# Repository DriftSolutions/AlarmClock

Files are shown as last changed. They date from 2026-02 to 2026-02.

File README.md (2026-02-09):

# Touchscreen Alarm Clock

A 3D printed touchscreen alarm clock with Home Assistant integration, designed for Raspberry Pi with a 5" display.

Pull Requests are welcome if you'd like to contribute.

## 3D Models

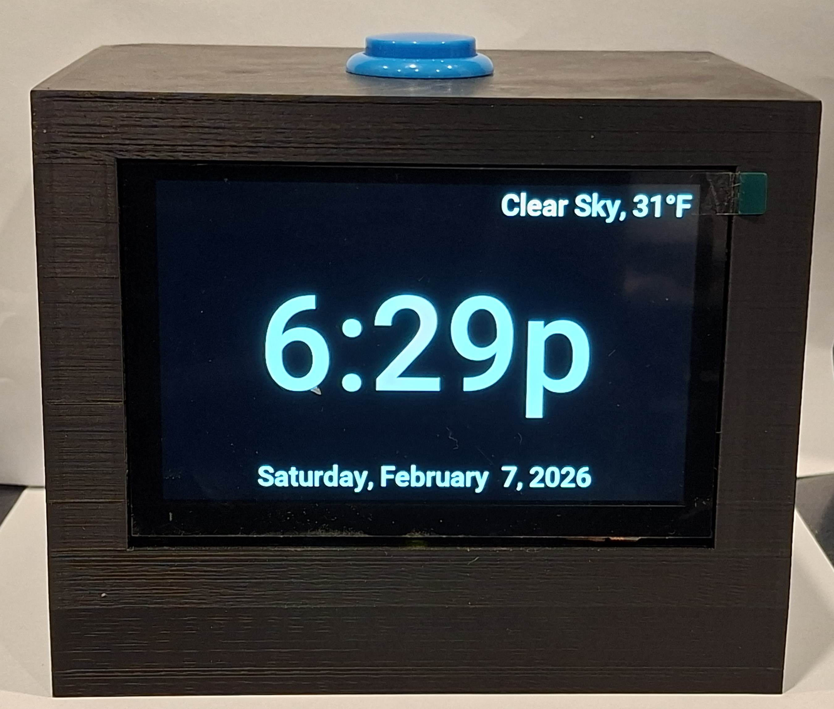
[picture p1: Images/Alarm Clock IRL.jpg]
Alarm Clock


[View Alarm Clock Main Body](STL%20Models/Alarm%20Clock%20-%20Main%20Body.stl)
[View Alarm Clock Rear Panel](STL%20Models/Alarm%20Clock%20-%20Rear%20Panel.stl)

## Screenshots

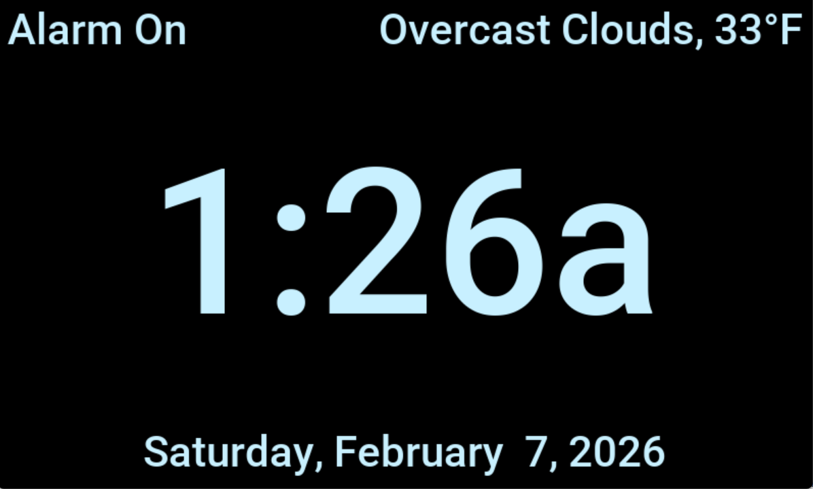
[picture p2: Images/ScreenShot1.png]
Alarm Clock Screenshot

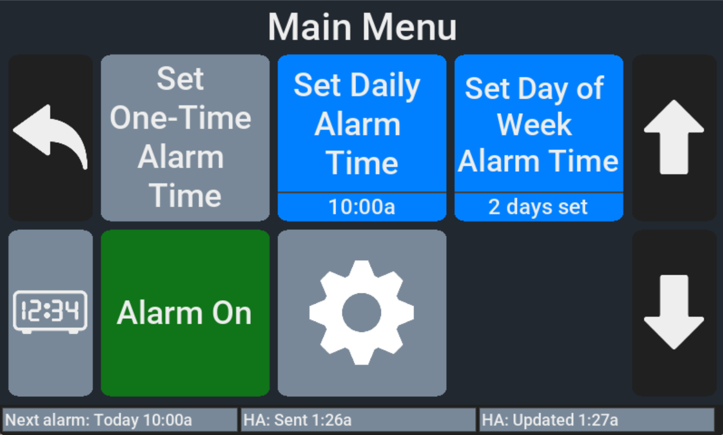
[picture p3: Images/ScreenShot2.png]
Main Menu Screenshot


## Features

- Large, easy-to-read time display
- Multiple alarm modes: one-time, daily, and per-day-of-week scheduling
- Automatic alarm re-enable at midnight option. For example if you have a one-time alarm set for 8:30am and your regular alarm at 9:00am it won't go off twice
- Automatic screen dimming at night. (Based on time of day or sun position)
- Optional Home Assistant integration for:
  - Weather & temperature display
  - Alarm state push synchronization to Home Assistant.
- Configurable screen timeout
- Touch-friendly menu interface

## Bill of Materials

| Component | Description | Link |
|---|---|---|
| Raspberry Pi 5 or 4B. A 3A/3A+/3B+ will probably also work, see notes below. | Main computer | [Buy on Amazon](https://www.amazon.com/dp/B0CK3L9WD3/) |
| Raspberry Pi 5 Cooler (probably optional, but it's only $10) | Cooler | [Buy on Amazon](https://www.amazon.com/dp/B0CLXZBR5P/) |
| MicroSD Card. I used a SanDisk High Endurance for reliability | Storage for OS and application | [Buy on Amazon](https://www.amazon.com/dp/B07P14QHB7/) |
| Hosyond 5" DSI Display | 800x480 capacitive touchscreen | [Buy on Amazon](https://www.amazon.com/dp/B0CXTFN8K9/) |
| USB Sound Card with Speakers | So you can hear the alarm going off | [Buy on Amazon](https://www.amazon.com/dp/B0CN1C1VPR/) |
| 4 count - M2.5x8 screws with washers | For mounting LCD panel | [Buy on Amazon](https://www.amazon.com/dp/B0FG2DQYY7/) |
| 4 to 8 count (use your judgement) - M2.5x8 or M3x8 screws with washers | For mounting rear panel | Included in kit above |
| 4 to 8 count (use your judgement) - M3x8 screws with washers | For mounting speakers | Included in kit above |
| Pi Power Supply | 5V 5A power supply for Pi 5 | [Buy on Amazon](https://www.amazon.com/dp/B07H125ZRL/) |
| 90 degree USB-C adapter | For Pi 5 power supply | [Buy on Amazon](https://www.amazon.com/dp/B0B2NJ3P3L/) |
| U-Shape/180 degree USB-A adapter. If you buy a different one watch the polarity of the end that connects to the Pi, it won't work if it's opposite from these. See [USB-C 180 Adapters.png](./Images/USB-C_180_Adapters.png) for an example. | For USB Sound Card | [Buy on Amazon](https://www.amazon.com/dp/B0BZ4M7FYH/) |
| Option 1: Adafruit 4259 USB-C to USB-A Jack and a 6" USB-A to USB-C Cable | Power inlet on the back of the case | [Buy on Amazon](https://www.amazon.com/dp/B082FNRPWL/) |
| Option 2: Adafruit 4261 USB-C to USB-C Jack and a 6" USB-C to USB-C Cable | Power inlet on the back of the case | [Buy on Adafruit](https://www.adafruit.com/product/4261) |
| Option 3: Skip the USB-C jack and print the cord retainer plug. The Pi power supply has a ferrite on it, you can put that inside the main unit and use the plug to keep the cord from being pulled and unplugged from the Pi | Power inlet on the back of the case | N/A |
| uxcell 30mm Arcade Button | For turning off the alarm when it's going off | [Buy on Amazon](https://www.amazon.com/dp/B07XYW58HV/) [They have other colors too](https://www.amazon.com/s?k=uxcell+30mm+Mounting+Hole+Game+Push+Button) |
| 2x ~20cm Jumper Wires with Dupont connectors on at least one end | For connecting the Arcade Button to the Pi | [Buy on Amazon](https://www.amazon.com/dp/B0BRTJQGS6) |
| 4x Small Rubber Feet (Cabinet Door/Drawer Bumpers) | For the bottom, for grip and to allow airflow in for cooling | [Buy on Amazon](https://www.amazon.com/dp/B08BR6CGWL) |
* For the power supplies / USB-C adapters, these will be different if you are using Pi 3's since they aren't USB-C.
* Where I'm using this I happen to have a UPS already to plug into for power reliability. I haven't checked it closely but [this UPS hat](https://www.amazon.com/GeeekPi-Raspberry-Uninterruptible-Management-Expansion/dp/B09NKFYHVK) might work, but you'd have to flip the standoffs over in the opposite direction from the pictures.

## How to Build

1. 3D Print both the main body and rear panel. I used PLA+ and 0.20mm Strength profile + Gyroid + PETG Support Interface (3MF included with this preset.) The PETG support inteface is optional, but will make your life easier. Printing upside down for the main body seemed to be the best compromise of time and support material used. You can do everything through step 7 while it's printing.
2. Use [Raspberry Pi Imager](https://www.raspberrypi.com/software/) to install Raspberry Pi OS onto your SD card. Pre-set the WiFi info and enable SSH for your convenience.
3. If applicable, install the Pi 5 cooler.
4. Install the Pi onto the rear of the screen following the directions in the screen's listing pictures for your Pi. Use the standoffs and 4 screws that come with the screen.
5. Insert the 90 degree USB-C adapter into the Pi's USB-C power port. *** Important: You must do this before installing the screen into the case or you'll have to take it back out ***
6. Insert the MicroSD card into the Pi.
7. Strip one end of the jumper wires, and solder them to the Arcade Button.
8. Install the screen into the case through the front, don't screw it in yet.
9. Connect your power supply temporarily to make sure the Pi boots up successfully and you can see the screen. If it's all good, power it off from the desktop with the touch screen, then unhook the power.
10. Use the 4 count M2.5x8 screws with washers to secure the LCD screen from the back of the case.
11. Insert the 180 degree USB-A adapter into the bottommost USB jack on the Pi that is closest to the rear of the case.
12. Install the Arcade Button through the top of the case, and connect the jumper wires to GPIO 17 (Pin 11) and GND (Pin 9). See [Raspberry_Pi_5_GPIO-Pinout.webp](./Images/Raspberry_Pi_5_GPIO-Pinout.webp) in Images folder for diagram.
### At this point, your alarm clock should look like this:
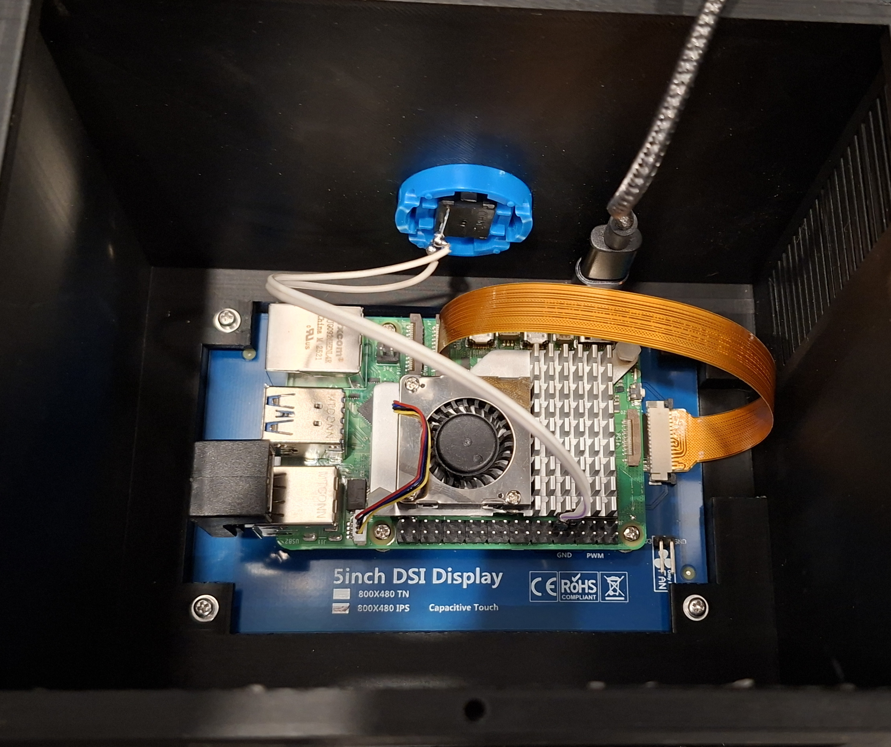
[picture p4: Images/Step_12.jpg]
View after Step 12


13. Install the 6" USB-C cable into the 90 degreee USB-C adapter.
14. Install the USB-C inlet jack into the rear panel. Don't connect the cable yet. The screw holes for the speakers should be pointing into the clock main body.
15. Use 4-8 M3x8 screws with washers to mount speakers to rear panel. I just put 2 in each on opposite corners and that seemed like plenty.
16. Connect the speaker wires to the USB sound card, then install the sound card into the 180 degree USB adapter through the rear of the clock body.
17. Connect the USB cable to the inside of the USB-C inlet through the rear of the clock body.
18. Use 4-8 count M2.5x8 or M3x8 screws with washers to secure rear panel. If M2.5 screws feel too loose in your print, step up to the M3.
19. Install 4x rubber feet on the bottom close to the corners.

## Software Installation

1. Boot up the Pi and SSH in.
2. Run: sudo /boot/firmware/config.txt

Look for the line that starts with dtparam=audio and make sure it is set to off. Then add this dtoverlay line after it (this makes the arcade button work):

```
dtparam=audio=off
dtoverlay=gpio-key,gpio=17,active_low=1,gpio_pull=up,keycode=28
```

Next, look for this line:
```
dtoverlay=vc4-kms-v3d
```
And change it to:
```
dtoverlay=vc4-kms-v3d,noaudio
```
This disables HDMI audio outputs so ALSA doesn't get confused and play audio to them instead of your USB speakers.

3. Install the required dependencies:

```bash
sudo apt install build-essential cmake pkg-config libcurl4-openssl-dev libunivalue-dev libsdl2-dev libsdl2-image-dev libsdl2-ttf-dev libsdl2-gfx-dev libsdl2-mixer-dev git
```

4. Run the following commands:

```bash
cd ~
git clone https://github.com/DriftSolutions/AlarmClock
cd AlarmClock/Output
cmake ../AlarmClock
make -j4
mv data/alarmclock.conf.example data/alarmclock.conf
nano data/alarmclock.conf
# Update alarmclock.conf with your settings here.
reboot
```

5. When the reboot is complete, SSH back in.

6. Set up a cronjob to auto-run your clock. You could also make a service file if you'd rather.
```
* * * * * cd /home/your_username/AlarmClock/Output && ./run_alarm_clock
```

7. If you are lucky you are all set, cron should start your alarm clock within a minute or you can run this command if you don't want to wait:
```bash
cd ~/AlarmClock/Output && ./cron_run_alarm_clock
```

8. Optional, upload your own custom sound files to ~/AlarmClock/Output/resources/alarms - it is of course safe to delete the stock ones too if you do. You'll have to kill alarm_clock for the new sound files to be picked up, since it only reads them once.

## Licenses

The software is licensed under the MIT license, see included LICENSE file.

The 3D models are licensed under [Creative Commons Attribution-NonCommercial-ShareAlike 4.0 International](https://creativecommons.org/licenses/by-nc-sa/4.0/) (CC BY-NC-SA 4.0)

The GUI graphics are from [Flaticon](https://www.flaticon.com/)

The credits for the included audio files are [here](./Output/resources/alarms/Included%20Audio%20Credits.txt)

Copyright (c) 2026 Drift Solutions

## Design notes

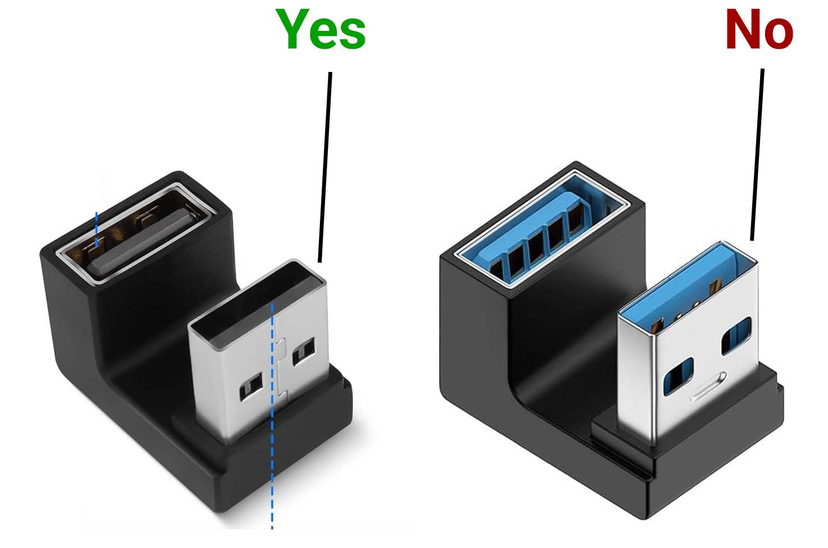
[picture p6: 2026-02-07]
Images/USB-C_180_Adapters.png

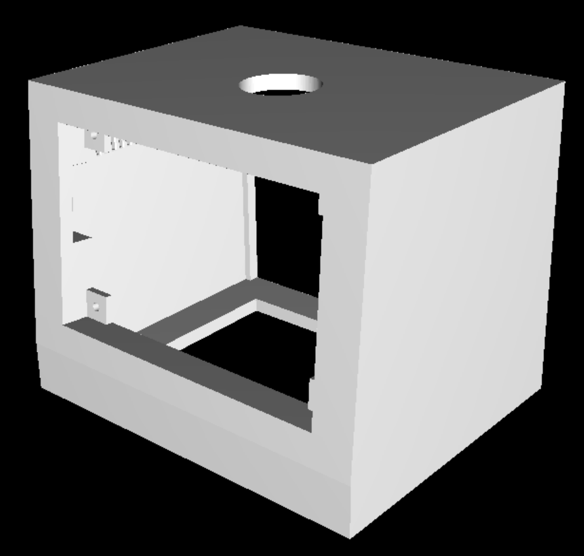
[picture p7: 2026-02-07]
Images/MainBodyRender.png

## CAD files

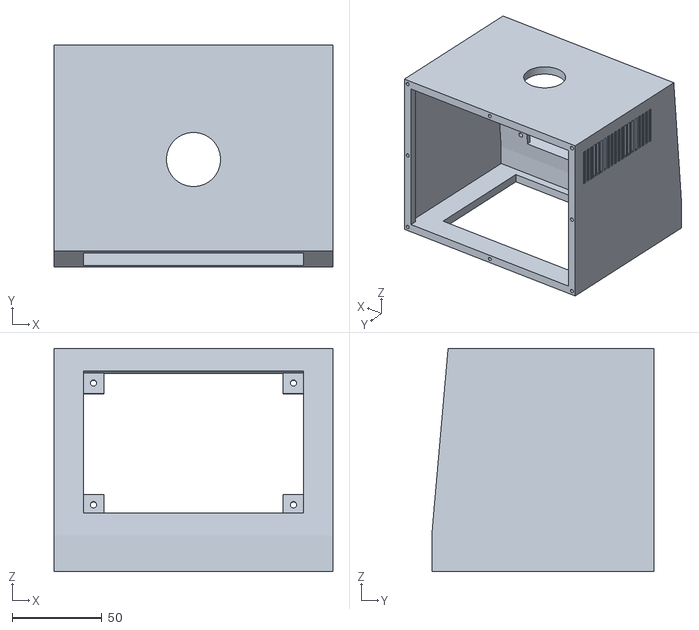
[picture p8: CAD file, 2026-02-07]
STL Models/Alarm Clock - Main Body.stl
155.0 x 123.6 x 124.0

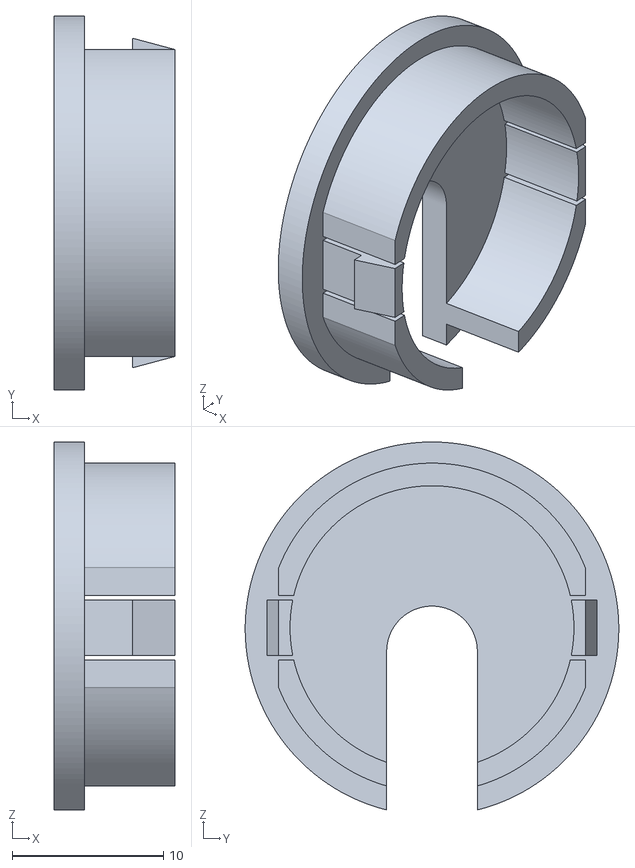
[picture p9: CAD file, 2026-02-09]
STL Models/Alarm Clock - Cord Retainer Plug.stl
8.00 x 24.7 x 24.4

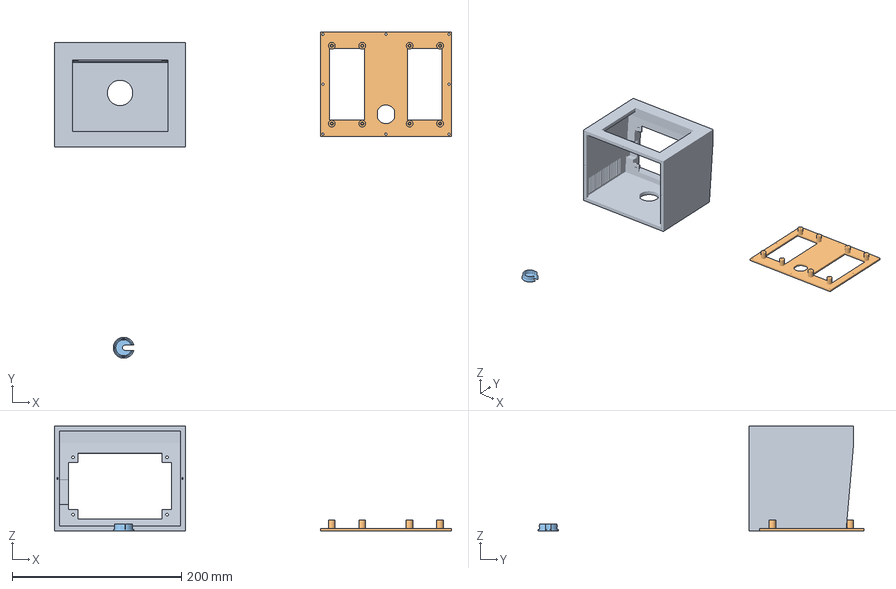
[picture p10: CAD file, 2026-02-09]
STL Models/Alarm Clock.3mf
469.3 x 385.8 x 124.0 mm
Alarm Clock - Main Body.stl
Alarm Clock - Rear Panel.stl
Alarm Clock - Cord Plug.stl

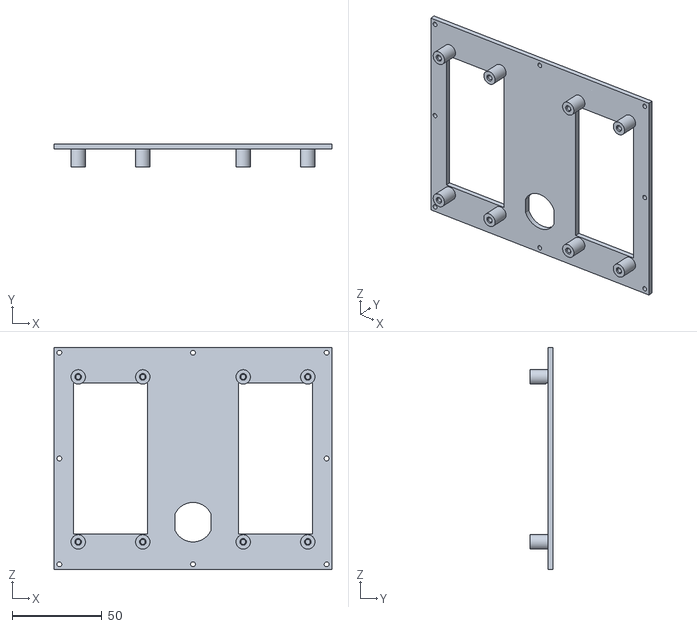
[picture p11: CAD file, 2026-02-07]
STL Models/Alarm Clock - Rear Panel.stl
155.0 x 13.0 x 124.0

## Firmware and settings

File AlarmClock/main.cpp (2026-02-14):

// SPDX-License-Identifier: MIT
// Copyright (c) 2026 Drift Solutions

#include "alarmclock.h"
extern "C" {
    #include "sunriset.h"
}

#ifdef WIN32
#pragma comment(lib, "Winmm.lib")
#pragma comment(lib, "SDL2.lib")
#pragma comment(lib, "SDL2_image.lib")
#pragma comment(lib, "SDL2_ttf.lib")
#pragma comment(lib, "SDL2_mixer.lib")
#ifdef DEBUG
#pragma comment(lib, "SDL2_gfx_d.lib")
#else
#pragma comment(lib, "SDL2_gfx.lib")
#endif
#endif

shared_ptr<AlarmConfig> cfg;
CONFIG config;
SDL_StatusBar status_bar;
shared_ptr<Page> page_clock;

// SDL2_mixer globals
Mix_Chunk* alarm_chunk = NULL;
int alarm_channel = -1;

const CONFIG_COLORS colors = {
    /* clock bg color */
    { 0x00, 0x00, 0x00, 0xFF },
    /* clock regular text */
    { 200, 240, 255, 0xFF },
    /* clock red text */
#ifdef WIN32
    { 0x60, 0, 0, 0xFF },
#else
    { 0xEE, 0, 0, 0xFF },
#endif

    /* menu page bg color */
    { 0x21, 0x28, 0x30, 0xFF },
    /* menu page text color */
    { 0xEE, 0xEE, 0xEE, 0xFF },

    /* normal */
    { 0x78, 0x88, 0x98, 0xFF }, // { 0x99, 0x99, 0x99, 0x99 }, // { 0x2E, 0x2E, 0x2E, 0xFF },
    { 0xEE, 0xEE, 0xEE, 0xFF },

    /* highlight */
    { 0x00, 0x80, 0xFF, 0xFF },
    { 0xEE, 0xEE, 0xEE, 0xFF },

    /* off */
    { 0xFF, 0x00, 0x00, 0x80 },
    { 0xEE, 0xEE, 0xEE, 0xFF },

    /* on */
    { 0x00, 0xC0, 0x00, 0x80 },
    { 0xEE, 0xEE, 0xEE, 0xFF },

    /* inactive */
    { 0x20, 0x20, 0x20, 0xFF },
    { 0x80, 0x80, 0x80, 0xFF },

    /* frame */
    { 0x42, 0x42, 0x42, 0xFF },
};

map<int, TTF_Font *> fonts;
TTF_Font* GetFontSize(int ptSize) {
    auto x = fonts.find(ptSize);
    if (x != fonts.end()) {
        return x->second;
    }

    auto font = TTF_OpenFont("resources/roboto.ttf", ptSize);
    if (font == NULL) {
        printf("Error opening font with point size %d: %s\n", ptSize, TTF_GetError());
        return NULL;
    }

    fonts[ptSize] = font;
    return font;
}

map<int, TTF_Font*> mono_fonts;
TTF_Font* GetMonoFontSize(int ptSize) {
    auto x = mono_fonts.find(ptSize);
    if (x != mono_fonts.end()) {
        return x->second;
    }

    auto font = TTF_OpenFont("resources/roboto_mono.ttf", ptSize);
    if (font == NULL) {
        printf("Error opening font with point size %d: %s\n", ptSize, TTF_GetError());
        return NULL;
    }

    mono_fonts[ptSize] = font;
    return font;
}

void shutdown(int err = 0) {
    printf("Shutting down...\n");
    config.shutdown_now = true;

    while (DSL_NumThreads()) {
        safe_sleep(1);
    }

    if (Mix_Init(0)) {
        Mix_HaltChannel(-1);
        if (alarm_chunk != NULL) {
            Mix_FreeChunk(alarm_chunk);
            alarm_chunk = NULL;
        }

        Mix_CloseAudio();
        Mix_Quit();
    }

    status_bar.Reset();

    for (auto& f : fonts) {
        TTF_CloseFont(f.second);
    }
    fonts.clear();
    for (auto& f : mono_fonts) {
        TTF_CloseFont(f.second);
    }
    mono_fonts.clear();
    if (config.backup_font != NULL) {
        TTF_CloseFont(config.backup_font);
        config.backup_font = NULL;
    }

    if (TTF_WasInit()) {
        TTF_Quit();
    }

    if (config.mWnd != NULL) {
        SDL_DestroyWindow(config.mWnd);
        config.mWnd = NULL;
    }
    if (config.mRenderer != NULL) {
        SDL_DestroyRenderer(config.mRenderer);
        config.mRenderer = NULL;
    }

    if (SDL_WasInit(SDL_INIT_VIDEO)) {
        SDL_Quit();
    }

    cfg.reset();

    exit(err);
}

void fatal_error(const string& msg, int err = 1) {
    printf("%s\n", msg.c_str());
#ifdef WIN32
    SDL_ShowSimpleMessageBox(SDL_MESSAGEBOX_ERROR, "Fatal Error", msg.c_str(), config.mWnd);
#endif
    shutdown(err);
}

void on_resize();

bool init() {
    cfg->ReadConfigFile();

    config.use_sun = cfg->GetBoolArg("-use_sun", false);
    config.lcd_brightness_fn = cfg->GetArg("-lcd_brightness_fn", "/sys/class/backlight/11-0045/brightness");
    config.home_assistant.url = cfg->GetArg("-home_assistant_url");
    config.home_assistant.token = cfg->GetArg("-home_assistant_token");
    config.home_assistant.alarm_entity = cfg->GetArg("-home_assistant_alarming");
    config.home_assistant.alarm_enabled_entity = cfg->GetArg("-home_assistant_alarm_enabled");
    config.home_assistant.next_alarm_entity = cfg->GetArg("-home_assistant_next_alarm");

    load_dynamic_settings();

    //Initialize SDL
    printf("Init SDL...\n");
    if (SDL_Init(SDL_INIT_VIDEO | SDL_INIT_AUDIO) < 0) {
        fatal_error(mprintf("SDL could not initialize! SDL Error: %s\n", SDL_GetError()));
    }
    SDL_SetHint(SDL_HINT_RENDER_SCALE_QUALITY, "best");

    printf("Init SDL_mixer...\n");
    if (Mix_Init(MIX_INIT_OGG | MIX_INIT_MP3 | MIX_INIT_FLAC | MIX_INIT_OPUS) == 0) {
        fatal_error(mprintf("SDL_mixer could not initialize! Error: %s\n", Mix_GetError()));
    }

    printf("Opening sound device...\n");
    if (Mix_OpenAudio(MIX_DEFAULT_FREQUENCY, MIX_DEFAULT_FORMAT, 2, 2048) < 0) {
        fatal_error(mprintf("Error opening audio! Error: %s\n", Mix_GetError()));
    }

    printf("Creating window...\n");
    config.win_size = {
        clamp<int>((int)cfg->GetIntArg("-width", WINDOW_WIDTH), 200, 4096),
        clamp<int>((int)cfg->GetIntArg("-height", WINDOW_HEIGHT), 200, 4096)
    };
    config.fullscreen = cfg->GetBoolArg("-fullscreen", true);

    //Create window
    config.mWnd = SDL_CreateWindow("Drift Alarm Clock", SDL_WINDOWPOS_CENTERED, SDL_WINDOWPOS_CENTERED, config.win_size.w, config.win_size.h, SDL_WINDOW_ALLOW_HIGHDPI | (config.fullscreen ? SDL_WINDOW_FULLSCREEN_DESKTOP : 0));
    if (config.mWnd == NULL) {
        fatal_error(mprintf("Window could not be created! SDL Error: %s\n", SDL_GetError()));
    }

    //SDL_SetWindowMinimumSize(config.mWnd, 400, 400);
    if (!config.fullscreen) {
        if (config.normal_win_position.x != INT_MAX && config.normal_win_position.y != INT_MAX) {
            SDL_SetWindowPosition(config.mWnd, config.normal_win_position.x, config.normal_win_position.y);
        }
    }

    config.mRenderer = SDL_CreateRenderer(config.mWnd, -1, SDL_RENDERER_ACCELERATED);
    if (config.mRenderer == NULL) {
        fatal_error(mprintf("Renderer could not be created! SDL Error: %s\n", SDL_GetError()));
    }

#ifndef WIN32
    SDL_ShowCursor(SDL_FALSE);
#endif

    /*
#ifdef WIN32
    int i;
    if ((i = SDL_GetWindowDisplayIndex(config.mWnd)) < 0) {
        i = 0;
    }
    float dpi_w, dpi_h;
    if (SDL_GetDisplayDPI(i, NULL, &dpi_w, &dpi_h) != 0 || dpi_w <= 0 || dpi_h <= 0) {
        dpi_w = dpi_h = 96;
    }
    //config.win_size.w, config.win_size.h
    int adj_w = int(dpi_w * 4.76f);
    int adj_h = int(dpi_h * 3.75f);
    SDL_SetWindowSize(config.mWnd, adj_w, adj_h);
    SDL_RenderSetLogicalSize(config.mRenderer, WINDOW_WIDTH, WINDOW_HEIGHT);
#endif
*/

    printf("Init SDL_ttf...\n");
    if (TTF_Init() != 0) {
        fatal_error(mprintf("Error initializing SDL_ttf! TTF Error: %s\n", TTF_GetError()));
    }

    config.backup_font = TTF_OpenFont("resources/roboto.ttf", 14);
    if (config.backup_font == NULL) {
        fatal_error(mprintf("Error loading backup font! TTF Error: %s\n", TTF_GetError()));
    }

    {
        shared_ptr<SDL_StatusBarSection> sec;
        /*
        status_bar.AddSection(sec);
        sec->align = SBA_LEFT;
        sec->SetSizingPercent(100);
        */

        int posw, posh;
        TTF_SizeUTF8(GetFontSize(STATUS_FONT_SIZE), "FPS: 1000", &posw, &posh);

        status_bar.AddSection(sec);
        sec->align = SBA_LEFT;
        sec->SetSizingPercent(33);

        //shared_ptr<SDL_StatusBarSection> sec;
        //SB_MPOS
        status_bar.AddSection(sec);
        sec->align = SBA_LEFT;
        sec->SetSizingPercent(33);

        status_bar.AddSection(sec);
        sec->align = SBA_LEFT;
        sec->SetSizingPercent(33);

        /*
        //SB_GPOS
        status_bar.AddSection(sec);
        sec->align = SBA_CENTER;
        sec->SetSizingFixed(posw);
        sec->status_text = "Grid Position in Paper Units";

        //SB_PPOS
        status_bar.AddSection(sec);
        sec->align = SBA_CENTER;
        sec->SetSizingFixed(posw);
        sec->status_text = "Physical Mouse Position in Paper";

        //SB_STATUS
        status_bar.AddSection(sec);
        sec->align = SBA_LEFT;
        sec->SetSizingPercent(65);
        sec->status_text = "Status Message(s)";

        //SB_SELECTED
        status_bar.AddSection(sec);
        sec->align = SBA_LEFT;
        sec->SetSizingPercent(35, max(posw, 200));
        sec->status_text = "Selected Object(s) Info";
        */

#ifdef DEBUG_FPS
        //SB_FPS
        status_bar.AddSection(sec);
        sec->align = SBA_CENTER;
        sec->SetSizingFixed(posw);
#endif

        if (!config.home_assistant.isValid()) {            
            statusbar_set(SB_HOME_ASSISTANT_RECV, "HA: Disabled");
        }
        if (!config.home_assistant.needToSendUpdates()) {
            statusbar_set(SB_HOME_ASSISTANT_SEND, "HA: Disabled");
        }
    }

    {
        shared_ptr<Menu> m = make_shared<Menu>();
        m->title = "Sidebar Menu";

        shared_ptr<MenuItem> i = make_shared<MenuItem>();
        i->rc = config.menu_buttons.back;
        i->text = "Back";
        i->image = "back.png";
        i->on_press_return = MCR_BACK;
        m->items.push_back(i);

        i = make_shared<MenuItem>();
        i->rc = config.menu_buttons.home;
        i->text = "Clock";
        i->image = "clock.png";
        i->on_press_return = MCR_CLOCK;
        m->items.push_back(i);

        i = make_shared<MenuItem>();
        i->rc = config.menu_buttons.prev;
        i->text = "Prev";
        i->image = "up.png";
        i->on_press_return = MCR_PREV_PAGE;
        m->items.push_back(i);

        i = make_shared<MenuItem>();
        i->rc = config.menu_buttons.next;
        i->text = "Next";
        i->image = "down.png";
        i->on_press_return = MCR_NEXT_PAGE;
        m->items.push_back(i);

        config.side_menu = m;
    }

    on_resize();

    if (config.home_assistant.isValid()) {
        start_home_assistant();
    }

    return true;
}

void load_dynamic_settings() {
    string data;
    if (!file_get_contents(cfg->GetDataDirFile("settings.json"), data)) {
        return;
    }
    UniValue obj(UniValue::VOBJ);
    if (!obj.read(data)) {
        return;
    }

    config.options.FromUniValue(obj);
}

void save_dynamic_settings() {
    UniValue obj(UniValue::VOBJ);
    config.options.ToUniValue(obj);

    string fn = cfg->GetDataDirFile("settings.json");
    
    if (backup_file(fn)) {
        file_put_contents(fn, obj.write(1));
    }
}


#define BUTTON_SPACE_HOR 10
#define BUTTON_SPACE_VERT 10
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
int main(int argc, const char* argv[]) {
#endif
    dsl_init();
    atexit(dsl_cleanup);

    cfg = make_shared<AlarmConfig>();
    cfg->ParseParameters(argc, argv);

    if (!init()) {
        shutdown();
    }

    //Enable text input
    //SDL_StartTextInput();
    set_fps_target(30);

#ifdef DEBUG_FPS
    int64 cur_sec = 0;
    int cur_frame = 0;
#endif

    printf("Loaded and ready.\n");

    //While application is running
    SDL_Event event;
    while (!config.shutdown_now) {
        Uint64 frame_start = SDL_GetTicks64();

        alarm_loop();
        tick_30s();
        if (config.home_assistant.isValid()) {
            update_home_assistant();
        }

        if (config.next_page) {
            SetPage(config.next_page);
        }
        if (config.cur_page.get() == NULL) {
            switch_to_clock();
        }
        if (config.cur_page.get() == NULL) {
            continue;
        }

        //Handle events on queue
        while (SDL_PollEvent(&event) != 0) {
            //User requests quit
            if (event.type == SDL_QUIT) {
                config.shutdown_now = true;
            } else if (event.type == SDL_WINDOWEVENT) {
                if (event.window.event == SDL_WINDOWEVENT_RESIZED || event.window.event == SDL_WINDOWEVENT_SIZE_CHANGED) {
                    on_resize();
                } else if (event.window.event == SDL_WINDOWEVENT_MOVED) {
                    if (!config.fullscreen) {
                        config.normal_win_position.x = event.window.data1;
                        config.normal_win_position.y = event.window.data2;
                    }
                    on_resize();
                }
            } else if (event.type == SDL_MOUSEMOTION) {
                update_mouse_position((int)event.motion.x, (int)event.motion.y);
                //handle_mouse_motion(event);
            } else if (event.type == SDL_MOUSEBUTTONUP) {
                update_mouse_position((int)event.button.x, (int)event.button.y);
                if (event.button.button == 1) {
                    SDL_Point pt = { (int)event.button.x, (int)event.button.y };
                    config.cur_page->OnClick(pt);
                }
            } else if (event.type == SDL_KEYDOWN) {
                handle_keypresses(event);
            }
        }

        config.cur_page->Tick();

        render();

        Uint64 frame_end = SDL_GetTicks64();
        if (frame_end >= frame_start) {
            Uint64 took = frame_end - frame_start;
            if (took < config.fps_target) {
                SDL_Delay(config.fps_target - Uint32(took));
            }
        }
        config.cur_frame++;
#ifdef DEBUG_FPS
        cur_frame++;
        if (time(NULL) != cur_sec) {
            statusbar_set(SB_FPS, mprintf("FPS: %d", cur_frame));
            cur_frame = 0;
            cur_sec = time(NULL);
        }
#endif
    }

    //Disable text input
    //SDL_StopTextInput();
    if (!config.fullscreen && config.normal_win_position.x != INT_MAX && config.normal_win_position.y != INT_MAX) {
        //cfg->SetIntArg("-winx", config.normal_win_position.x);
        //cfg->SetIntArg("-winy", config.normal_win_position.y);
        save_dynamic_settings();
    }

    shutdown();
    return 0;
}

void CONFIG::Alarm() {
    if (!_alarming) {
        printf("Alarm!\n");
        _alarming = true;
    }
}

void CONFIG::ClearAlarm() {
    if (_alarming) {
        printf("Alarm acknowledged, shutting up now...\n");
        _alarming = false;
        if (config.options.auto_enable_at_midnight) {
            printf("Disabling alarm until midnight...\n");
            config.options.enable_alarm = false;
            save_dynamic_settings();
        }
    }
}

void CONFIG::SetIsDark(bool dark) {
    if (dark != is_dark) {
        if (dark) {
            printf("It is now dark outside...\n");
        } else {
            printf("It is now light outside...\n");
        }
        _is_dark = dark;
        if (config.cur_page) {
            config.cur_page->OnDarkChanged();
        }
        update_lcd_brightness();
    }
}

void statusbar_set(SB_SECTIONS sec, const string& str) {
    status_bar.SetSectionText(sec, str);
}

void statusbar_set_progress(SB_SECTIONS sec, size_t cur, size_t max) {
    shared_ptr<SDL_StatusBarSection> s;
    if (status_bar.GetSection(sec, s)) {
        s->progress_current = cur;
        s->progress_max = max;
    }
}

bool ConfigOptions::ShouldAlarmAt(time_t ts, tm* ptm) {
    struct tm* tm = ptm;
    if (ptm == NULL) {
        static struct tm _tm;
        localtime_r(&ts, &_tm);
        tm = &_tm;
    }

    vector<ALARM_TIME> opts;
    if (one_time_alarm.isValid()) {
        opts.push_back(one_time_alarm);
    }
    if (daily_alarms[tm->tm_wday].isValid()) {
        opts.push_back(daily_alarms[tm->tm_wday]);
    } else if (alarm_time.isValid()) {
        opts.push_back(alarm_time);
    }

    for(auto& o : opts) {
        if (o.hour == tm->tm_hour && o.minute == tm->tm_min) {
            if (o.hour == one_time_alarm.hour && o.minute == one_time_alarm.minute) {
                one_time_alarm.hour = -1;
                one_time_alarm.minute = -1;
                save_dynamic_settings();
            }
            return true;
        }
    }
    return false;
}

time_t ConfigOptions::GetNextAlarmTime(time_t start) const {
    struct tm tm;
    localtime_r(&start, &tm);
    tm.tm_sec = 0;
    return GetNextAlarmTime(tm);
}

time_t ConfigOptions::GetNextAlarmTime(const struct tm& start) const {
    assert(start.tm_wday >= 0 && start.tm_wday <= 6);
    assert(start.tm_sec == 0);

    vector<ALARM_TIME> opts;
    if (one_time_alarm.isValid()) {
        opts.push_back(one_time_alarm);
    }
    if (daily_alarms[start.tm_wday].isValid()) {
        // If there is a day of week alarm time for this day, then use it
        opts.push_back(daily_alarms[start.tm_wday]);
    } else if (alarm_time.isValid()) {
        // Otherwise, use the regular daily alarm time
        opts.push_back(alarm_time);
    }

    time_t ret = 0;
    for (auto& o : opts) {
        if (o.hour > start.tm_hour || (o.hour == start.tm_hour && o.minute >= start.tm_min)) {
            struct tm tm2 = start;
            tm2.tm_hour = o.hour;
            tm2.tm_min = o.minute;
            time_t ts = mktime(&tm2);
            if (ts >= 0 && (ret == 0 || ts < ret)) {
                ret = ts;
            }
        }
    }

    return ret;
}

time_t ConfigOptions::GetNextAlarmTime() const {
    time_t start = time(NULL);
    time_t ret = GetNextAlarmTime(start);
    int days = 0;
    while (ret <= 0 && days++ < 7) {
        start += 86400;
        struct tm tm;
        localtime_r(&start, &tm);
        tm.tm_hour = tm.tm_min = tm.tm_sec = 0;
        ret = GetNextAlarmTime(tm);
    }
    return ret;
}

static void AlarmTimeToUniValue(const ALARM_TIME& at, UniValue& obj) {
    obj.setObject();
    obj.pushKV("hour", at.hour);
    obj.pushKV("minute", at.minute);
}

static bool AlarmTimeFromUniValue(ALARM_TIME& at, const UniValue& obj) {
    if (!obj.isObject()) {
        return false;
    }
    if (obj.exists("hour") && obj["hour"].isNum()) {
        at.hour = obj["hour"].get_int();
    }
    if (obj.exists("minute") && obj["minute"].isNum()) {
        at.minute = obj["minute"].get_int();
    }
    return true;
}

static UniValue PointToUniValue(const SDL_Point& at) {
    UniValue obj(UniValue::VARR);
    obj.push_back(at.x);
    obj.push_back(at.y);
    return obj;
}

static bool PointFromUniValue(SDL_Point& at, const UniValue& obj) {
    if (!obj.isArray() || obj.size() != 2) {
        return false;
    }
    if (!obj[0].isNum() || !obj[1].isNum()) {
        return false;
    }
    at.x = obj[0].get_int();
    at.y = obj[1].get_int();
    return true;
}

void ConfigOptions::ToUniValue(UniValue& obj) {
    obj.setObject();
    obj.pushKV("enable_alarm", enable_alarm);
    obj.pushKV("dim_when_dark", dim_when_dark);
    obj.pushKV("auto_enable_at_midnight", auto_enable_at_midnight);
    obj.pushKV("flip_clock_style", flip_clock_style);
    obj.pushKV("time_format", int64(time_format));    
    obj.pushKV("screen_timeout", screen_timeout / 1000);

    UniValue ota(UniValue::VOBJ);
    AlarmTimeToUniValue(one_time_alarm, ota);
    obj.pushKV("one_time_alarm", ota);

    UniValue at(UniValue::VOBJ);
    AlarmTimeToUniValue(alarm_time, at);
    obj.pushKV("alarm_time", at);

    UniValue da(UniValue::VARR);
    for (int i = 0; i < 7; i++) {
        UniValue day(UniValue::VOBJ);
        AlarmTimeToUniValue(daily_alarms[i], day);
        da.push_back(day);
    }
    obj.pushKV("daily_alarms", da);

    if (!config.fullscreen) {
        obj.pushKV("window_pos", PointToUniValue(config.normal_win_position));
    }
}
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

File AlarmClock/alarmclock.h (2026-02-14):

// SPDX-License-Identifier: MIT
// Copyright (c) 2026 Drift Solutions

#pragma once
#define SDL_MAIN_HANDLED
//#define DEBUG_FPS
#ifndef DSL_STATIC
#define DSL_STATIC
#endif
#ifndef ENABLE_CURL
#define ENABLE_CURL
#endif
/*
#ifndef ENABLE_SQLITE
#define ENABLE_SQLITE
#endif
#ifndef ENABLE_LIBEVENT
#define ENABLE_LIBEVENT
#endif
*/
#include <drift/dsl.h>
#include <SDL.h>
#include <SDL_main.h>
#include <SDL_image.h>
#include <SDL_mixer.h>
#include <SDL2_gfxPrimitives.h>
#include <SDL_ttf.h>
#include <univalue.h>

#define WINDOW_WIDTH 800
#define WINDOW_HEIGHT 480

#define BUTTONS_PER_ROW 4
#define BUTTONS_PER_COL 2
#define NUM_BUTTONS ((BUTTONS_PER_ROW - 1) * BUTTONS_PER_COL)

#define TITLE_FONT_SIZE 42
#define TIME_FONT_SIZE 400
#define FLIP_TIME_FONT_SIZE 100
#define ALARM_FONT_SIZE 96
#define MENU_FONT_SIZE 36
#define FOOTER_FONT_SIZE 24
#define STATUS_FONT_SIZE 22

#define ALERT_CHANNEL 0

#define printf ac_printf
void ac_printf(const char* pszFormat, ...);

typedef struct SDL_Size {
	int w;
	int h;
} SDL_Size;

#include "menus.h"
#include "status_bar.h"
#include "config.h"
extern shared_ptr<AlarmConfig> cfg;

struct CONFIG_COLORS {
	SDL_Color clock_bg;
	SDL_Color clock_text;
	SDL_Color clock_red_text;

	SDL_Color menu_page_bg;
	SDL_Color menu_page_text;
	SDL_Color menu_normal_bg;
	SDL_Color menu_normal_text;
	SDL_Color menu_highlight_bg;
	SDL_Color menu_highlight_text;
	SDL_Color menu_off_bg;
	SDL_Color menu_off_text;
	SDL_Color menu_on_bg;
	SDL_Color menu_on_text;
	SDL_Color menu_inactive_bg;
	SDL_Color menu_inactive_text;
	SDL_Color menu_frame;
};
extern const CONFIG_COLORS colors;

class Page {
public:
	virtual void Tick() {};

	virtual void OnActivate() {};
	virtual void OnDarkChanged() {}
	virtual void OnClick(const SDL_Point& pt) {}

	virtual void Render() = 0;
};

void SetNextPage(shared_ptr<Page>& p);
void switch_to_clock();
void switch_to_menu_settings();
void switch_to_menu(shared_ptr<Menu>& menu);

struct ALARM_TIME {
	int hour = -1;
	int minute = -1;

	bool isValid() const {
		return (hour >= 0 && hour <= 23 && minute >= 0 && minute <= 59);
	}
};

enum TIME_FORMATS {
	TF_12HOUR_SUFFIX,
	TF_12HOUR_PLAIN,
	TF_24HOUR,
	TF_NUM_FORMATS
};

class ConfigOptions {
public:
	bool enable_alarm = false;
	bool dim_when_dark = true;
	bool auto_enable_at_midnight = false;
	bool flip_clock_style = false;
	TIME_FORMATS time_format = TF_12HOUR_SUFFIX;
	// If there is no activity, it will return to the clock display after this long
#ifdef DEBUG
	uint64 screen_timeout = 30000;
#else
	uint64 screen_timeout = 15000;
#endif

	ALARM_TIME one_time_alarm;
	ALARM_TIME alarm_time;
	ALARM_TIME daily_alarms[7];

	void ToUniValue(UniValue& obj);
	bool FromUniValue(const UniValue& obj);

	bool ShouldAlarmAt(time_t ts, struct tm* ptm = NULL);
	time_t GetNextAlarmTime() const;
	time_t GetNextAlarmTime(time_t tme) const;
	time_t GetNextAlarmTime(const struct tm& tm) const;
};

class HomeAssistantInfo {
public:
	int64 last_update = 0;

	bool is_dark = false;
	string weather;
	double temp = DBL_MIN;
	string temp_unit;

	bool hadRecentUpdate() const {
		return (last_update >= time(NULL) - 1800);
	}
};
bool GetHomeAssistantInfo(HomeAssistantInfo& info);

void load_dynamic_settings();
void save_dynamic_settings();
void update_lcd_brightness();

class CONFIG {
private:
	bool _alarming = false;
	bool _is_dark = false;

	bool got_lcd_brightness = false;
	uint8 cur_lcd_brightness = 0;
public:
	bool shutdown_now = false;
	FILE* log_fp = NULL;

	ConfigOptions options;

	const bool& alarming = _alarming;
	void Alarm();
	void ClearAlarm();

	bool use_sun = false;
	const bool& is_dark = _is_dark;
	void SetIsDark(bool dark);

	string lcd_brightness_fn;
	bool get_lcd_brightness(uint8& val);// 0-255
	bool set_lcd_brightness(uint8 val);

	struct {
		string url, token;
		bool isValid() const {
			return (!url.empty() && !token.empty());
		}

		string alarm_entity, next_alarm_entity, alarm_enabled_entity;
		bool needToSendUpdates() const { 
			if (isValid()) {
				return (!alarm_entity.empty() || !next_alarm_entity.empty() || !alarm_enabled_entity.empty());
			}
			return false;
		}
		HomeAssistantInfo info;
	} home_assistant;

	Uint32 fps = 0;
	Uint32 fps_target = 0;
	uint32 cur_frame = 0;

	bool fullscreen = false;
	SDL_Window* mWnd = NULL;
	SDL_Renderer* mRenderer = NULL;

	SDL_Point normal_win_position = { INT_MAX, INT_MAX };
	SDL_Size win_size = { 0 };
	SDL_Rect title_area = { 0 };
	SDL_Rect main_area = { 0 };
	SDL_Rect status_area = { 0 };

	TTF_Font* backup_font = NULL;

	SDL_Point mpos = { 0,0 }; //mouse/finger pos in window pixels

	SDL_Rect menu_area = { 0 };
	struct {
		SDL_Rect back = { 0 };
		SDL_Rect home = { 0 };
		SDL_Rect prev = { 0 };
		SDL_Rect next = { 0 };
		SDL_Rect buttons[NUM_BUTTONS] = { 0 };
	} menu_buttons;

	shared_ptr<Menu> side_menu;
	shared_ptr<Menu> next_menu;

	shared_ptr<Page> cur_page;
	shared_ptr<Page> next_page;
};
extern CONFIG config;

enum SB_SECTIONS {
	SB_NEXT_ALARM,
	SB_HOME_ASSISTANT_SEND,
	SB_HOME_ASSISTANT_RECV,
#ifdef DEBUG_FPS
	SB_FPS,
#endif
};
void statusbar_set(SB_SECTIONS sec, const string& str);
void statusbar_set_progress(SB_SECTIONS sec, size_t cur, size_t max);
extern SDL_StatusBar status_bar;

TTF_Font* GetFontSize(int ptSize);
TTF_Font* GetMonoFontSize(int ptSize);

void draw_text(TTF_Font* font, int x, int y, const SDL_Color& col, const char* str, int style = TTF_STYLE_NORMAL);
void draw_text(TTF_Font* font, int x, int y, const SDL_Color& col, const vector<string>& lines, int style = TTF_STYLE_NORMAL);
enum DRAW_TEXT_ALIGNMENTS {
	DTA_LEFT = 1,
	DTA_CENTER = 2,
	DTA_RIGHT = 4,
	DTA_TOP = 8,
	DTA_MIDDLE = 16,
	DTA_BOTTOM = 32
};
void draw_text(TTF_Font* font, const SDL_Rect& rc, uint8 align, const SDL_Color& col, const string& str, int style = TTF_STYLE_NORMAL); // align = DRAW_TEXT_ALIGNMENTS
void draw_text(int ptSize, const SDL_Rect& rc, uint8 align, const SDL_Color& col, const string& str, int style);
void draw_text_wrapped(TTF_Font* font, const SDL_Rect& rc, uint8 align, const SDL_Color& col, const string& str, int style = TTF_STYLE_NORMAL); // doesn't size down font to fit rc
void draw_text_wrapped(int ptSize, const SDL_Rect& rc, uint8 align, const SDL_Color& col, const string& str, int style = TTF_STYLE_NORMAL); // sizes down font if needed to fit rc
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

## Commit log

2026-02-07 Add screenshots + main body STL
    [Alarm Clock - Main Body.stl]
2026-02-07 Added optional flip style clock, some cleanups
    [alarmclock.h, main.cpp]
2026-02-07 Add rear panel STL and 3MF
    [Alarm Clock - Rear Panel.stl, Alarm Clock.3mf]
2026-02-09 Couple of minor fixes
    [main.cpp]
2026-02-09 Add optional cord retainer plug
    [Alarm Clock - Cord Retainer Plug.stl, Alarm Clock.3mf]
2026-02-09 Some safety checks/bug prevention
    [alarmclock.h]
2026-02-14 Add a Home Assistant sensor for if the alarm is enabled or not
